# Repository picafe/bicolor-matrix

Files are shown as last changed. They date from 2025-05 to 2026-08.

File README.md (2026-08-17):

# bicolor-matrix

> **This repository has moved to [bicolor-matrix-v2](https://github.com/picafe/bicolor-matrix-v2).**

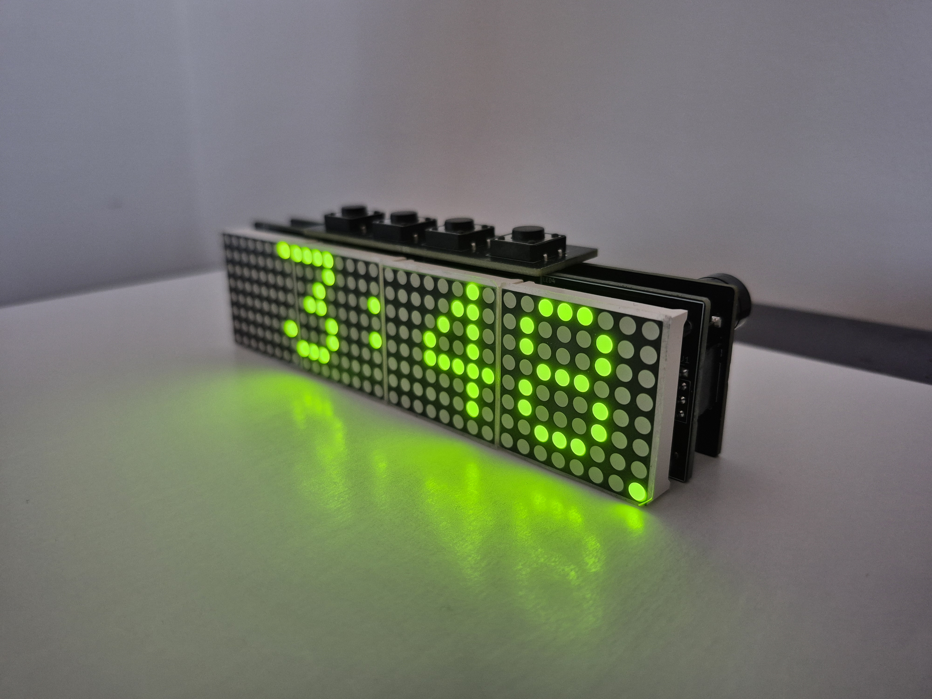
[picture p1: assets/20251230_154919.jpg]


A 32x8 bicolor LED matrix module composed of 4 8x8 matrices based on the Holtek HT16K33A I2C LED driver.

## Inspiration

Inspired by the common 32x8 red LED matrix modules that use the MAX7219 IC, I wanted to make my own module but with more colours and functionality, while keeping the same asthetic. 

I found [these](https://www.aliexpress.com/item/1005007029570407.html) modules while browsing Aliexpress and thought they could look be a cool alternative. With the red and light green variant, you can have red, a light green, and orange all in one module. As far as I'm aware, there aren't RGB modules in a similar form factor, although you can take generic WS2818 8x8 matricies and 3D print a diffuser for them, although the footprint is much bigger. This project was also partially inspired by [bitluni's LED magnet tiles](https://www.youtube.com/watch?v=L2J_eNgjxio) which I found really cool.

Unlike the single colour matricies with 16 pins, these had 24. I found [this](https://www.adafruit.com/product/902) Adafruit module and followed a similar schematic with the Holtek HT16K33A I2C LED driver, but with an inverted board layout, and with 4 modules on one PCB. This was my 2nd PCB project, so it was definately a big undertaking.

## Showcase

Matrix Board:
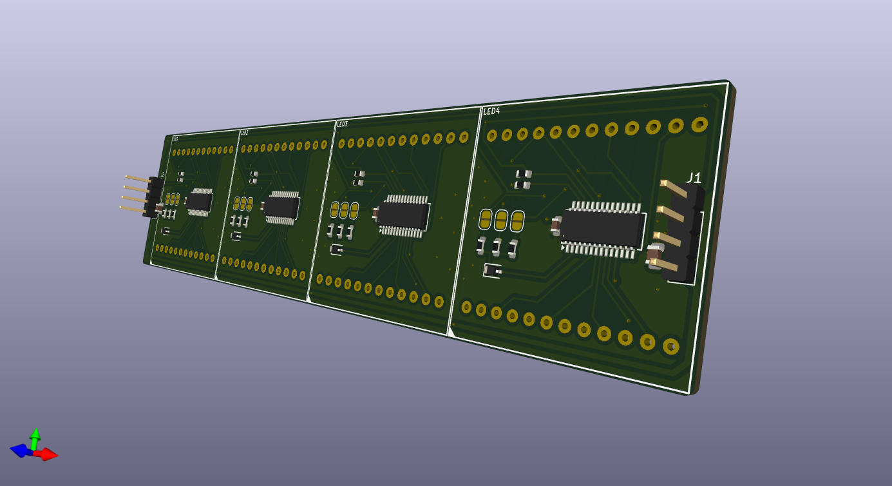
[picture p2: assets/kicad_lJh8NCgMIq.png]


Adapter Board:
This adds functionality through a RP2040 Zero board, a DS3231 module and a small buzzer, and a generic logic level shifter since the Holtek IC only operates near 5V.

Button Board:
An addition to the adapter board and provides 4 interface buttons for setting time

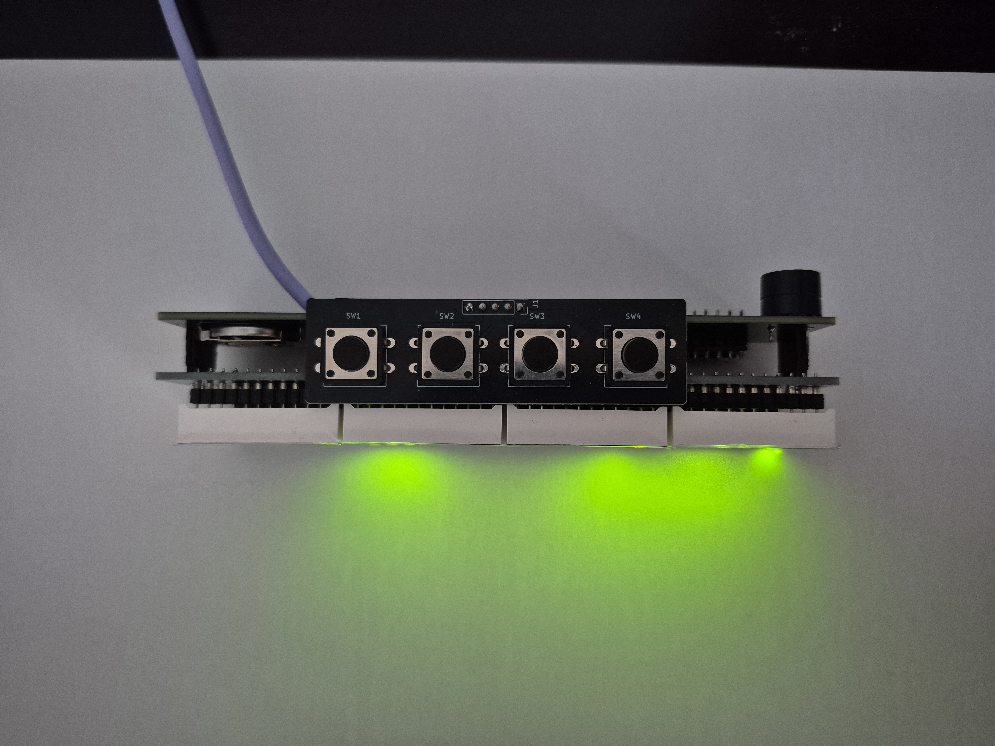
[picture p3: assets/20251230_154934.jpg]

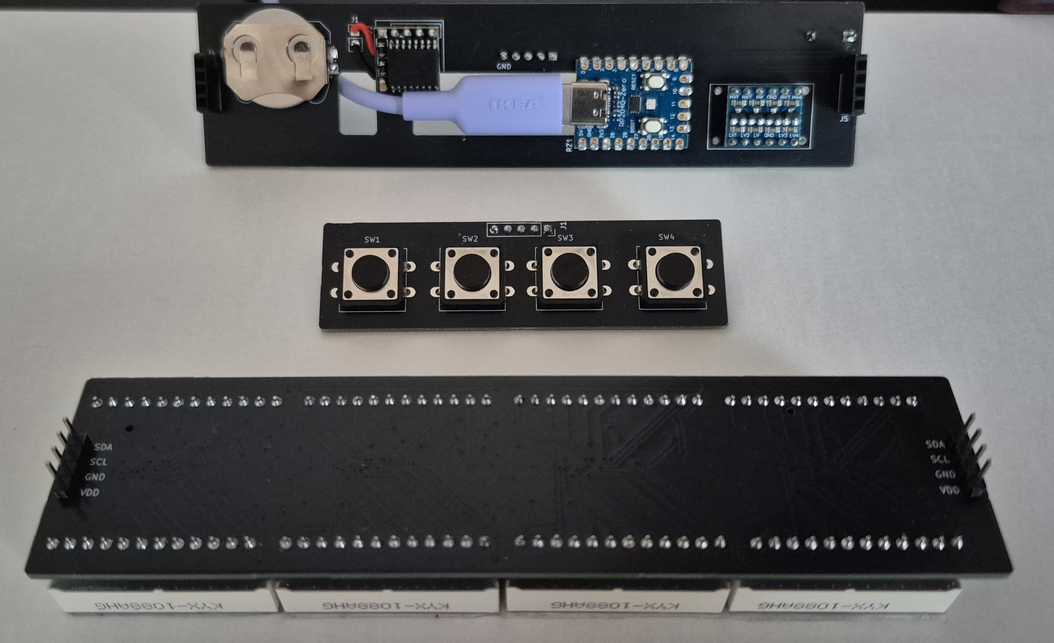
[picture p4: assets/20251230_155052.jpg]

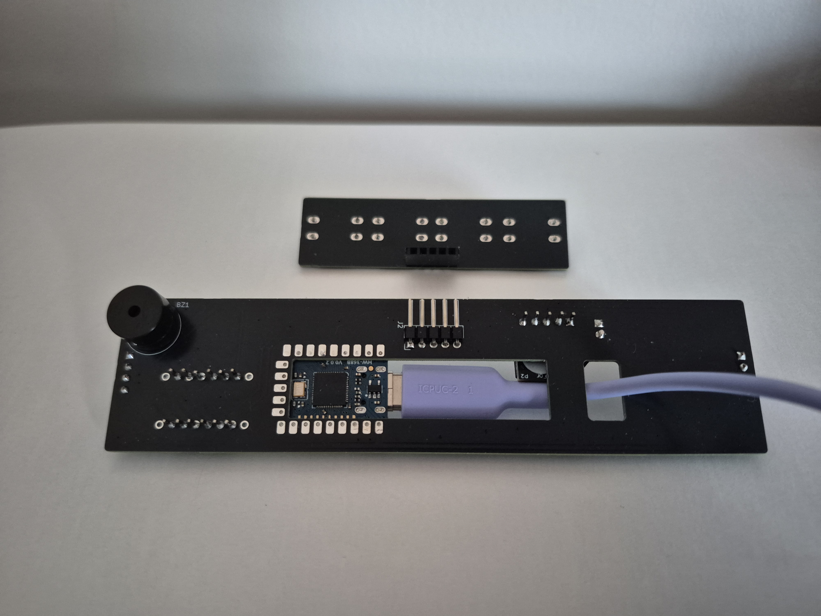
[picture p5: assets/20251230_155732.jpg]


## Bill of Materials (BOM) + Assembly Notes
Item | Quantity | Description
| -------- | ------- | ------- |
[Machine Pin Headers](https://www.aliexpress.com/item/10000000838267.html) | 5 Pcs | 2.54mm pitch circular pin headers to connect the LED matricies to the main PCB. These are needed such as to not solder the matrix boards directly to the PCB, allowing for easier replacement if needed.
12mm x 12mm Buttons | 4 | Generic 12mm tactile push buttons, whatever is cheapest on Aliexpress. I used [these](https://www.aliexpress.com/item/10000000838267.html).
RP2040 Zero | 1 | Microcontroller board, whatever is cheapest on Aliexpress. I bought from [here](https://www.aliexpress.com/item/1005007650325892.html).
[DS3231 Module](https://www.aliexpress.com/item/1005007143842437.html) | 1 | Mini module without the battery, basically a simple breakout. Use side cutters to cut the plastic on the pre-soldered female headers, then desolder each of the pins. Solder in male headers.
Level Shifter | 1 | 4-channel logic level shifter module, whatever is cheapest on Aliexpress. They are cheapest in packs of 10, so you can use the extra ones for other projects. I bought from [here](https://www.aliexpress.com/item/1005006765742290.html).
Buzzer | 1 | Generic 3.3V 7.6mm diameter buzzer, whatever is cheapest on Aliexpress.
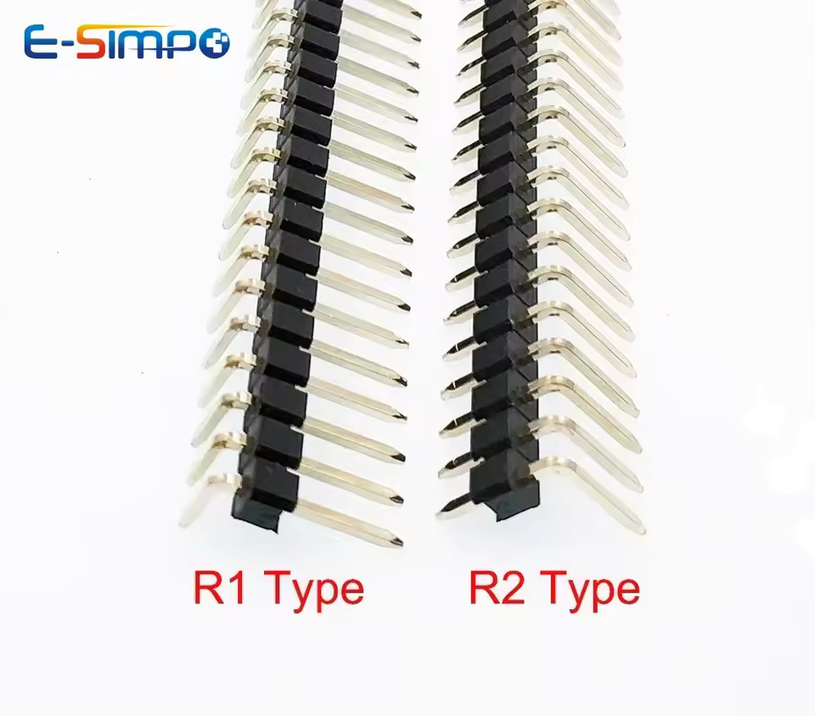
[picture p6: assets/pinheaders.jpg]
[Right Angle Pin Headers](https://www.aliexpress.com/item/32896209964.html) | 1 | Get the R1 type of pin headers pictured here, they're slightly more uncommon and more expensive than the R1 type. This is for the button board connection. 
2.54mm Pin Headers (Male and Female) | 1 | To connect the matrix board to the adapter board and general use. This [video](https://www.youtube.com/watch?v=qDG3VFSMSPQ) shows how to make custom length female headers.

Buying Note: I recommend you try to buy components on the Aliexpress mobile app (web on desktop doesn't seem to have a search bar) in Bundle Deals if you can find them as you can get better prices, and they usually ship faster.

Ordering Note: I recommend you to create your own adapter board for the project. The one I built has some design flaws (button board doesn't fit flush with the adapter board, the right angle headers need to be positioned lower, and usb connector placement could be improved).

It was designed to be a prototype and optimize costs, so I recommend you to make your own design based on your needs. I was browsing Aliexpress a few days ago and found this [RP2350 stamp module](https://www.aliexpress.com/item/1005008513193739.html) which would make a better alternative since you can position the USB connector anywhere on the PCB. It's also relatively cheap.

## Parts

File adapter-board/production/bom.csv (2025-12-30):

Designator | Footprint | Quantity | Value | LCSC Part #
BT1 | BatteryHolder_Keystone_3034_1x20mm | 1 | Battery_Cell
BZ1 | Buzzer_12x9.5RM7.6 | 1 | Buzzer
J1 | PinHeader_1x02_P2.54mm_Vertical | 1 | Conn_01x02_Socket
J2 | PinHeader_1x05_P2.54mm_Horizontal | 1 | Conn_01x05_Pin
J4, J5 | PinSocket_1x04_P2.54mm_Vertical | 2 | Conn_01x04_Socket
RZ1 | RP2040-Zero | 1 | RP2040-Zero
U1 | Generic-Level-Shifter | 1 | ~
U2 | PinHeader_1x05_P2.54mm_Vertical | 1 | ~

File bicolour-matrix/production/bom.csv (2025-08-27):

Designator | Footprint | Quantity | Value | LCSC Part #
C1, C6 | C_0805 | 2 | 10uF | C15850
C2, C3, C4, C5 | C_0603 | 4 | 1uF | C15849
D1, D2, D3, D4 | D_SOD-323 | 4 | 1N4148WS | C2128
J1, J2 | PinHeader_1x04_P2.54mm_Vertical | 2 | Conn_01x04_Pin
LED1, LED2, LED3, LED4 | SEGMENT_BICOL_BL-M12A883XX | 4 | DISP_SEGMENT_8X8_BICOLOR_ROWCATHODEMI2A883XX
R1, R12, R16, R17, R2, R6, R7, R8 | R_0603 | 8 | 4.7kΩ | C23162
R10, R11, R13, R14, R15, R18, R19, R20, R3, R4, R5, R9 | R_0603 | 12 | 47kΩ | C25819
U1, U2, U3, U4 | SSOP-28_3.9x9.9mm_P0.635mm | 4 | HT16K33A-28SSOP | C5444738

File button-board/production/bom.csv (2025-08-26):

Designator | Footprint | Quantity | Value | LCSC Part #
J1 | PinSocket_1x05_P2.54mm_Vertical | 1 | Conn_01x05_Socket
SW1, SW2, SW3, SW4 | SW_PUSH-12mm | 4 | SW_Push

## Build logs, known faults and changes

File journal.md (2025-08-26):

---
Title: "Bicolour Matrix PCB"
Author: "Surya"
Description: "Red and Green LED 32x8 Matrix with HT16K33A"
Created On: "19/5/2025"
---

## 2025-05-19
Four years ago, I built a custom clock with off-the-shelf parts (Arduino Nano, DS3231 breakout, 32x8 MAX7219 LED Matrix, all on a breadboard with 2 buttons). Although it has worked very reliably, only needing a few battery replacements and resetting the nano a few times, I want to make a custom solution.

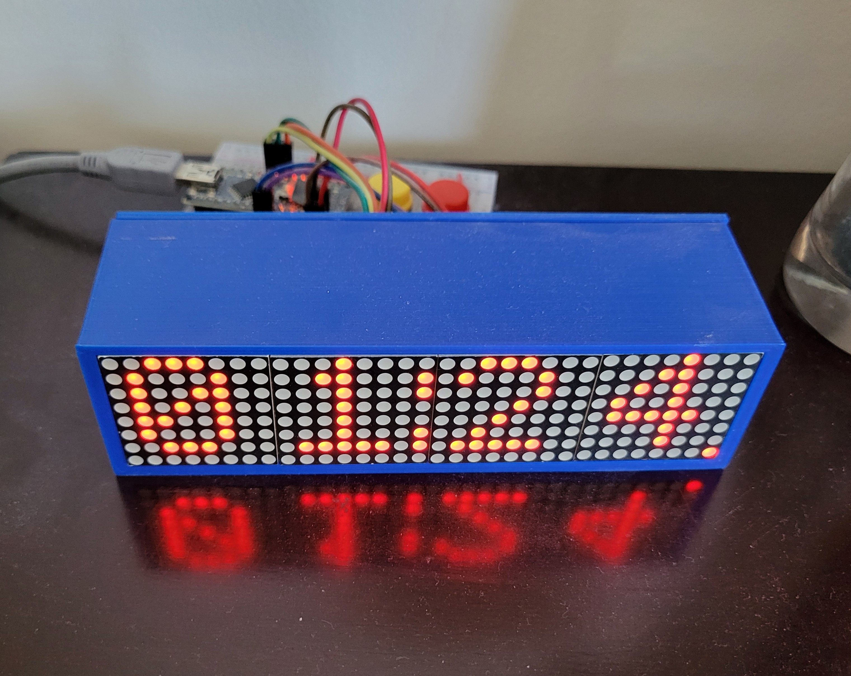
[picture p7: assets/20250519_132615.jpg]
A simple clock with a LED matrix with the current time in a blue case. An Arduino Nano and other components are in the background.

*the current solution ✨*

### Plans
Displays: https://www.aliexpress.com/item/1005007029570407.html
bicolour 8x8 led matrix !! (Red Yellow Green CC)
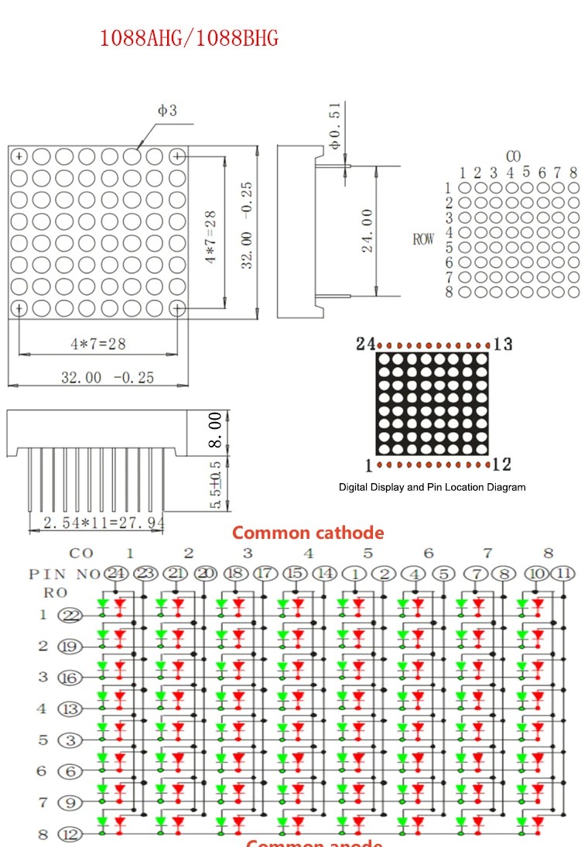
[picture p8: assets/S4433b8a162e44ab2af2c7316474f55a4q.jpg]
 \
Controller: Holtek HT16K33A
https://www.holtek.com/webapi/116711/HT16K33Av102.pdf
likely going to take inspiration from here: 
- https://www.adafruit.com/product/902
- https://learn.adafruit.com/adafruit-led-backpack/bi-color-8x8-matrix

Display Schematic (from Adafruit):
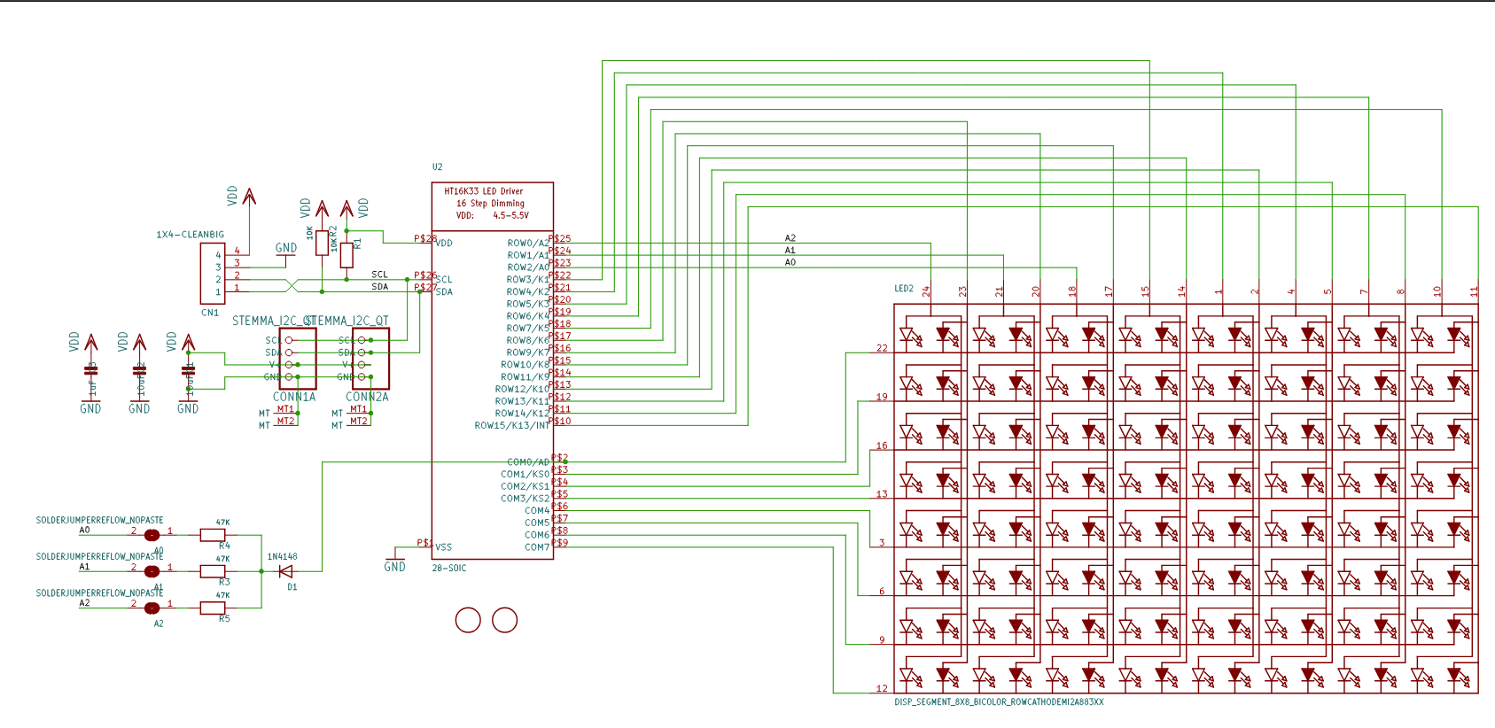
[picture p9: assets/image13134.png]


Using these connections (no STEMMA connectors, just 4 ICs wired on a PCB to same I2C bus with different addresses hard-set on each IC), I will probably make a similar PCB layout with these segments + a microcontroller (possibly a SMD rp2040-zero) with a RTC module and battery slot + controlls for time adjustment and screen brightness controll + an alarm feature. \
I could also use an ESP32 XIAO board and make a feature to add alarms with your phone (maybe also experiment with Zigbee?). I shall see. \
All rough ideas for now, I have some parts in mind but I will likely have to order the screens and a HT16K33(A) breakout board (https://www.aliexpress.com/item/1005006831500717.html) to see if this idea is feasible. If it is, this will be pretty epic.

hours spent: 4

## 2025-05-22
Ordered the 10 pack of LED matricies and the HT16K33 breakout board. I'll prototype with it and build a schematic based on that. The cost of the other components will likely not be much. Not much else for today.

hours spent: n/a

## 2025-05-26
I found this video a few days ago that popped into my YT rec: https://www.youtube.com/watch?v=7fNYj0EXxMs. The PCB design was shown for a few seconds and its quite interesting since he uses the same Holtek driver (along with an I2C address translator; LTC4316) to drive a row of 8 displays, each with 20 pins: 
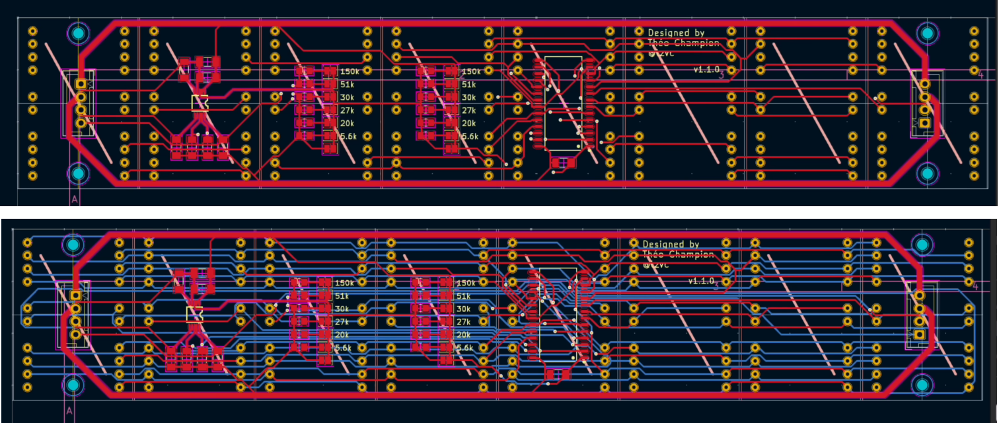
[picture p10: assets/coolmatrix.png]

I'll try and see what magic was performed here (since idk much about this) and see if I can emulate it !!
update: I decided to just go with 4 ICs chained together this is probably beyond my scope

hours spent: n/a

## 2025-05-30
The shipment of the LED matricies and breakout board arrived!! I will assemble them soon (according to the Adafruit schematic) with an arduino nano probably to test. One thing I noticied is that the breakout is kinda sketchy in quality (ive never seen such a thin pcb). Anwyays, it should be fine.

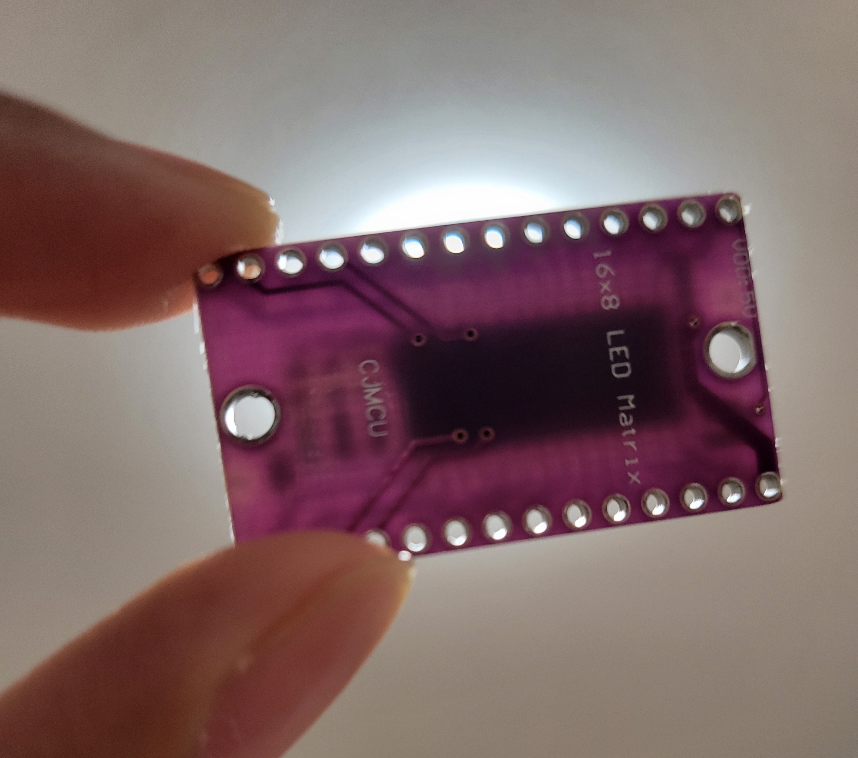
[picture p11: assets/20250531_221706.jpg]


hours spent: n/a

## 2025-06-03
Finally got time to wire everything together. Took me roughly 2hrs to make all the breadboard connections according to the schematic. But it works!\

I tested using the Adafruit example sketch. There are some buggy sections which I'll have to look into later, but for now it looks promising. I guess it's PCB design time. My updates might be less frequent since I'll be busy with a bunch of things.

hours spent: 2.5

## 2025-06-12
Its been a while (got busy) but finally got around to making the schematic (I made one copy and then copy pasted it 4 times; it should work for now). It took be a bit to import the LED controller IC symbol from easyeda (setting up easyeda2kicad and downloading plugins and stuff). The routing is kinda messy but we ball. Took me roughly 2-3hrs I lost track. 
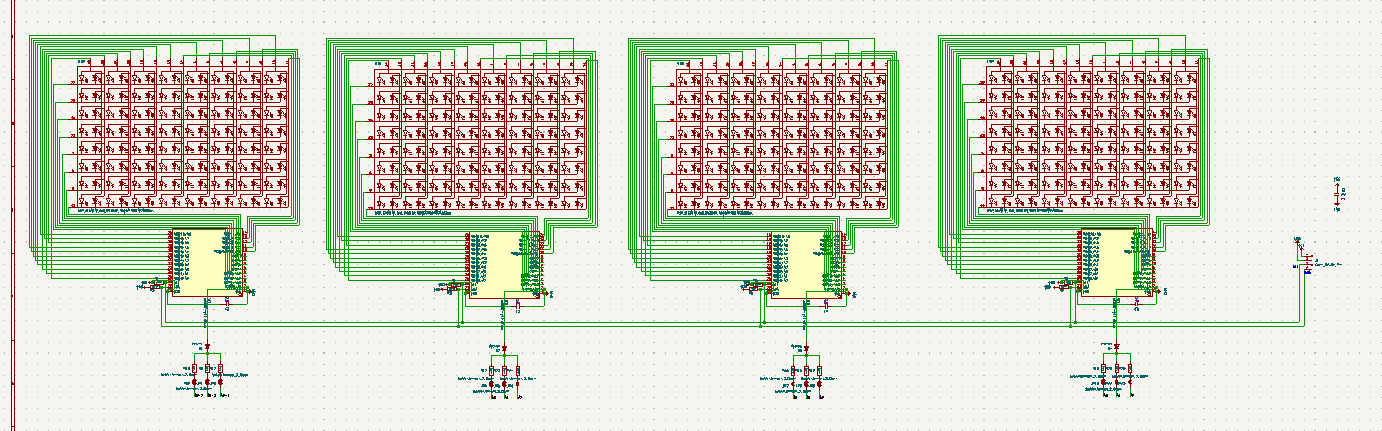
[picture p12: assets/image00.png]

I downloaded and imported the Adafruit board into KiCad so I can reference it while making mine, but my design will be pretty different since they mounted the display on the back of the PCB (mine will be in the front so the pins are mirrored/flipped)
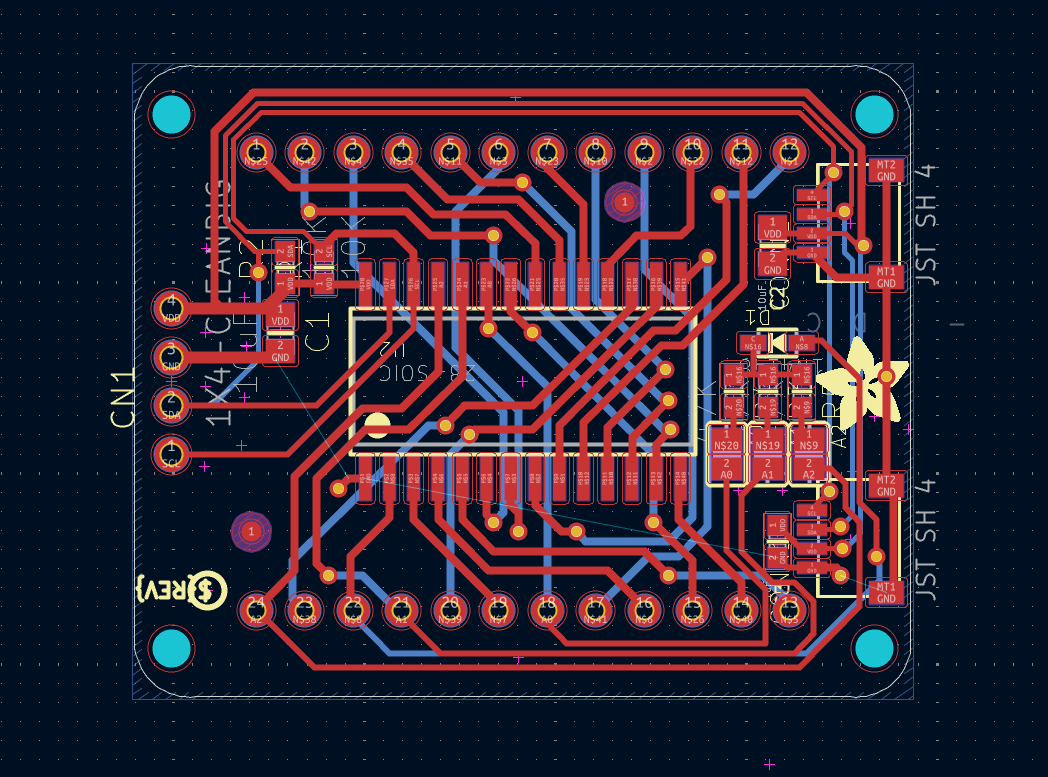
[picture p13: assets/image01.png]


hours spent: 3

## 2025-07-10
OKAY SO life happened. Starting the PCB was quite intimidating so I kind of clicked switch to PCB and left the project for a month. BUT I have convinced myself to get started. And yes it is a lot harder than I thought routing this is pretty pain since I've only done HC solder before. Will prob have to use a lot of vias. Not dealing with any important signals so I should be fine for the most part. \
Slight time skip but no picture for now since I had to delete all my traces a few times. Will be slaving away at this tomorrow.

hours spent: 3

## 2025-07-11
Some progress. Was pain, idk what I'm doing. Not much to say. Took me roughly an hour or 2. 
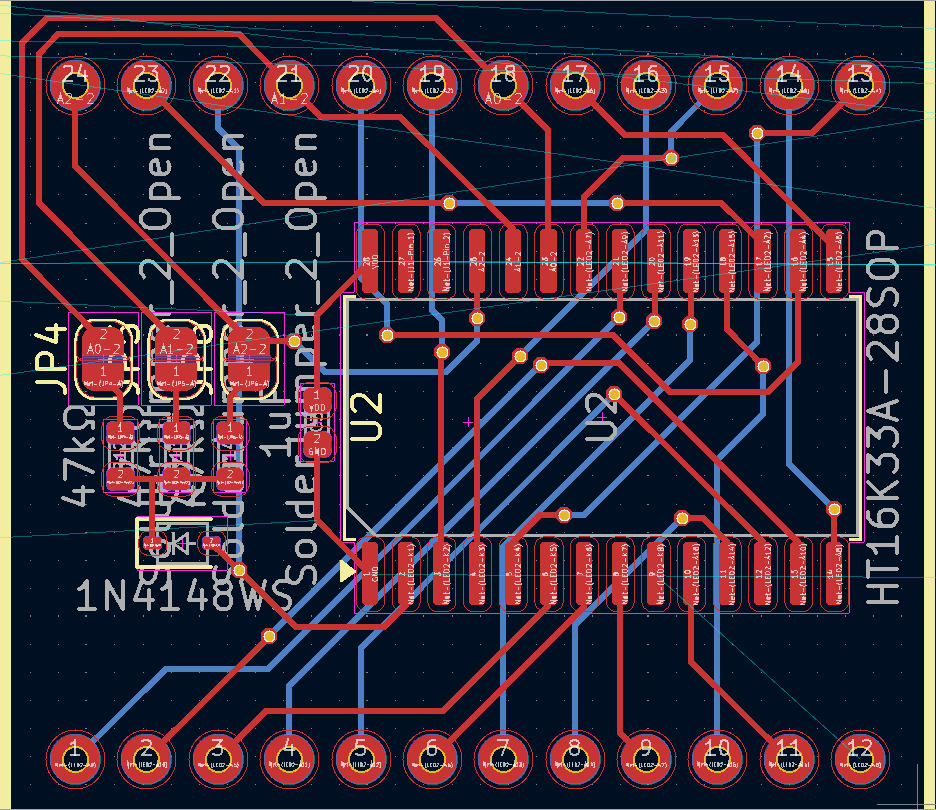
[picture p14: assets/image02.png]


hours spent: 2

## 2025-07-13
OKAY SO AFTER GOING THROUGH ALL THAT... I was using the SOP28 footprint for the LED driver when I meant to use SSOP28. Welp.. time to restart the routing again. Actually I'll do this tomorrow I'm tired.

hours spent: 1

## 2025-07-14
Honestly after this much practice, this is becoming not as hard anymore !! \
managed to get some decent progress:
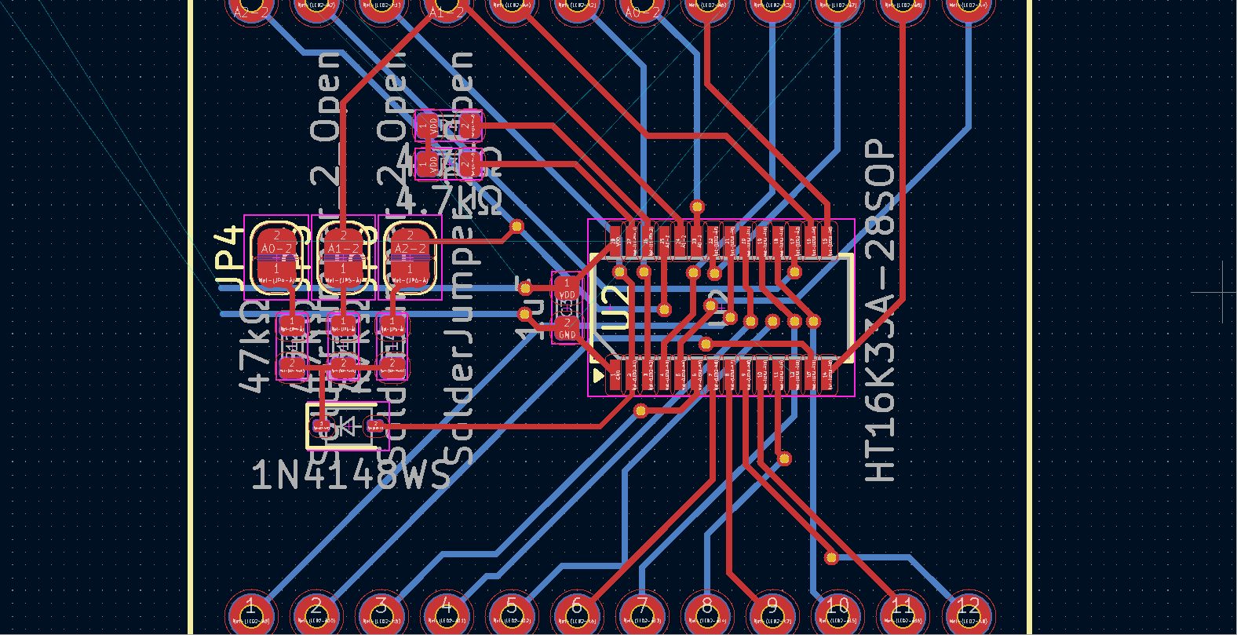
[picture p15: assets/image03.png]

took about 2hrs

hours spent: 2

## 2025-07-15
Finally pretty much done one module, but now I've realized that I can't really copy-paste the design over. I gotta use layout replication (https://www.youtube.com/watch?v=DBfI2wwno5o) and using a custom goofy schematic size wasn't the best idea. I thought I could get away with the jank 😔. I will do that soon. I will also upload the PCB to this repo soon but I'm editing this on WSL and my project folder is on Windows so I got a bit lazy in doing that until now.
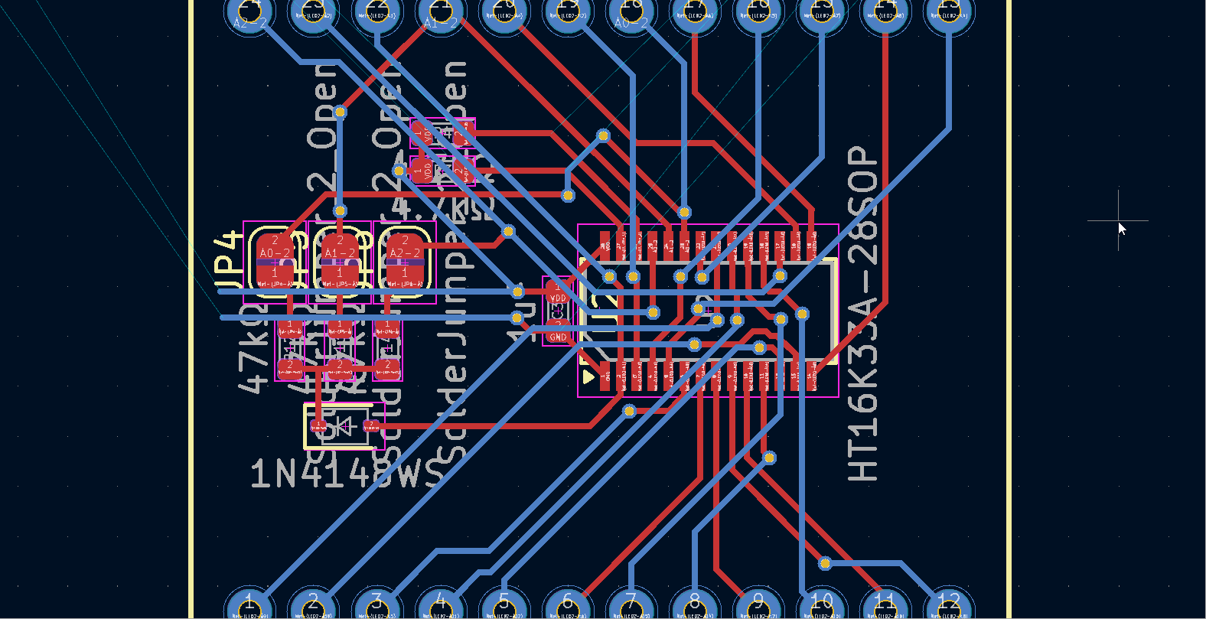
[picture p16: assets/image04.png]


hours spent: 2

## 2025-08-10
I just restarting working on it :pf:. Yet again got busy. Anyways, finally setup the replicate layout plugin (the guide was useful) and managed to 4x the layout properly. It took quite a while. I have yet to put the routing for connecting them all together, (and I still have no clue what I'm doing) but overall good progress today.

hours spent: 2

## 2025-08-12
Got some feedback from a friend and adjusted my routing a bit, and also synced it with the other 4 modules. I tried to route the power/gnd/i2c lines but my routing seems very sketchy. I'll try to improve on it tomorrow. Not much else to say.
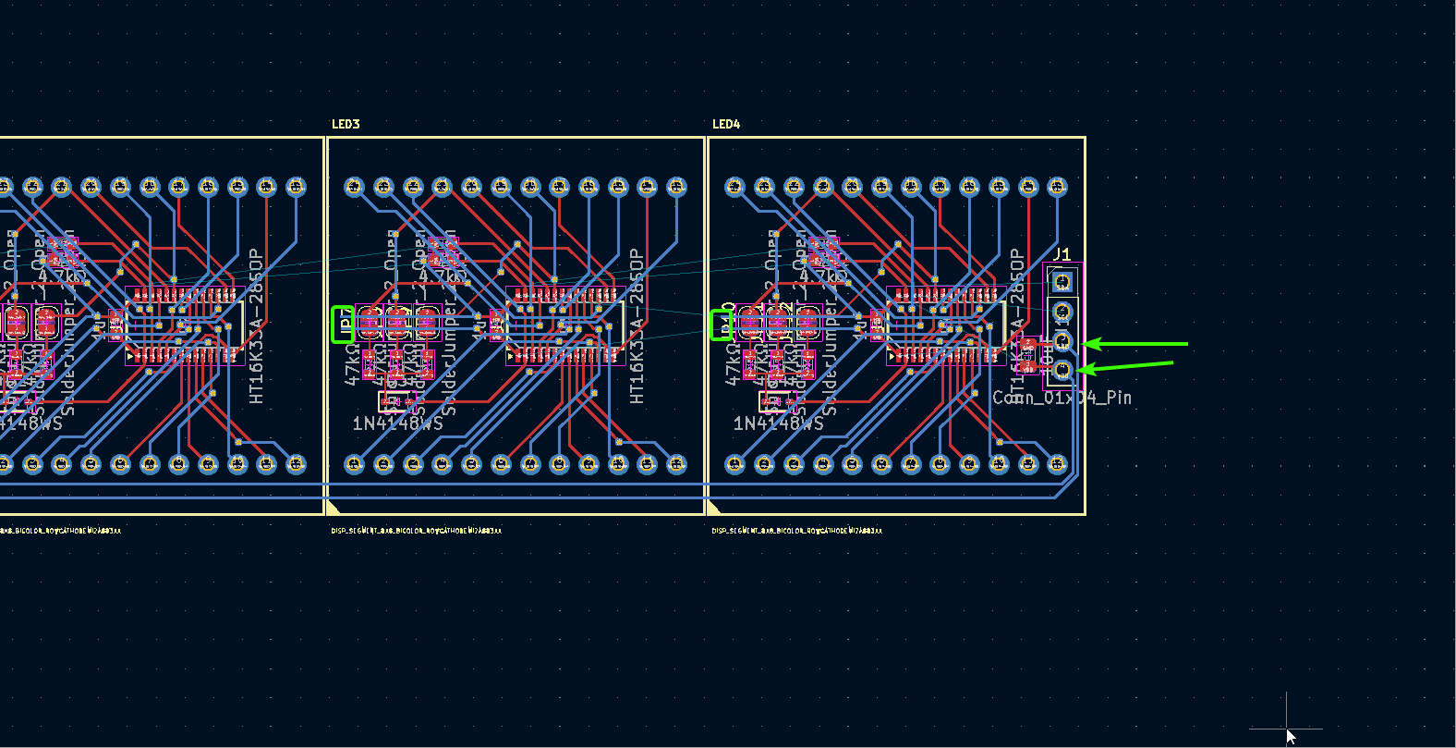
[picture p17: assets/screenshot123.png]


hours spent: 1

## 2025-08-13
I got some feedback from the Slack and added stitching vias to my ground plane (I did not know these were a thing). I also improved my layout further in terms of connecting it all together and adding polish (rounded corners, silkscreen, fixing small DRC warnings, etc.).

hours spent: 1.5

## 2025-08-15
Got some more feedback and everything seems to be good. I will verify the connections in the schematic a last time before I mark this part of the project as done. I also created the project and for now the schematic for the adapter/driver board to make a simple but smart clock. I'll add my sketches later but the 2 boards will probably be the same size with standard headers and I can right angle mount a top board with 2 headers using some right angle header pins I have. I just have to make sure the measurements are right.

hours spent: 1

## 2025-08-19
Just started to work on the adapter board. The schematic was quite easy to make but had to make a real quick custom symbol for the DS3231 module I already had. It's slightly scuffed but not too bad. I'm thinking of using an ESP32 as clicking a bunch of buttons to set an alarm seems cumbersome especially since I usually don't have a static alarm time. It feels like something easier set on your phone. I don't have much more time today so I will start the PCB tomorrow.
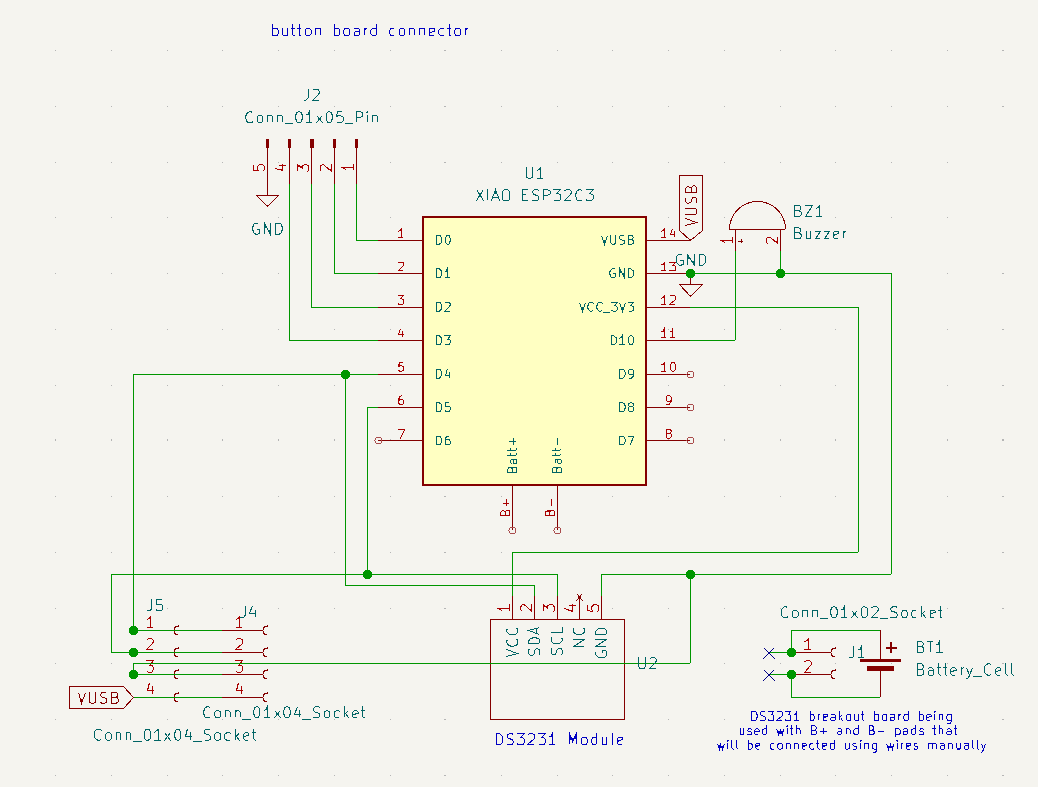
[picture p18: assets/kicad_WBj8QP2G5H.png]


hours spent: 1

## 2025-08-19

I thought of adding a small breadboard-style layout to the PCB if i wanted to tack on some components in the future with some wires. Made a quick custom footprint for that (and random symbol since it doesn't really matter).
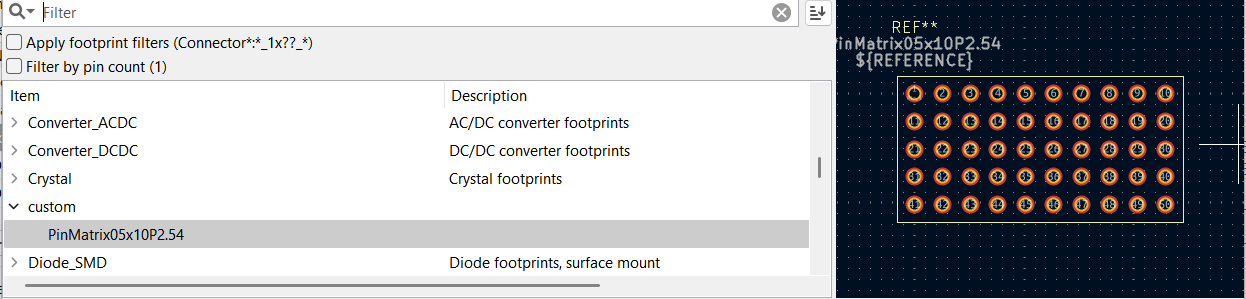
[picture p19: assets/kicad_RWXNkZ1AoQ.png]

I started work on the PCB and I've gotten decent progress. I want to power the thing through the USB on the ESP32, so I am trying to add clearance for that. The range doesn't have to be amazing since I very likely won't be setting my alarm from another room. This is more of a personally tailored PCB rather than something that suits everyone.

hours spent: 2

# 2025-08-21

I originally only allocated space for 2 buttons, but later changed it to 4, since I'll probably need more for the function I want. I don't like the idea of having the time to be dependent on the internet, so I'd like the option to set time time up up/down controls, a button to switch the display colours and a button to toggle/snooze the alarm. I am mostly done the PCB I believe.

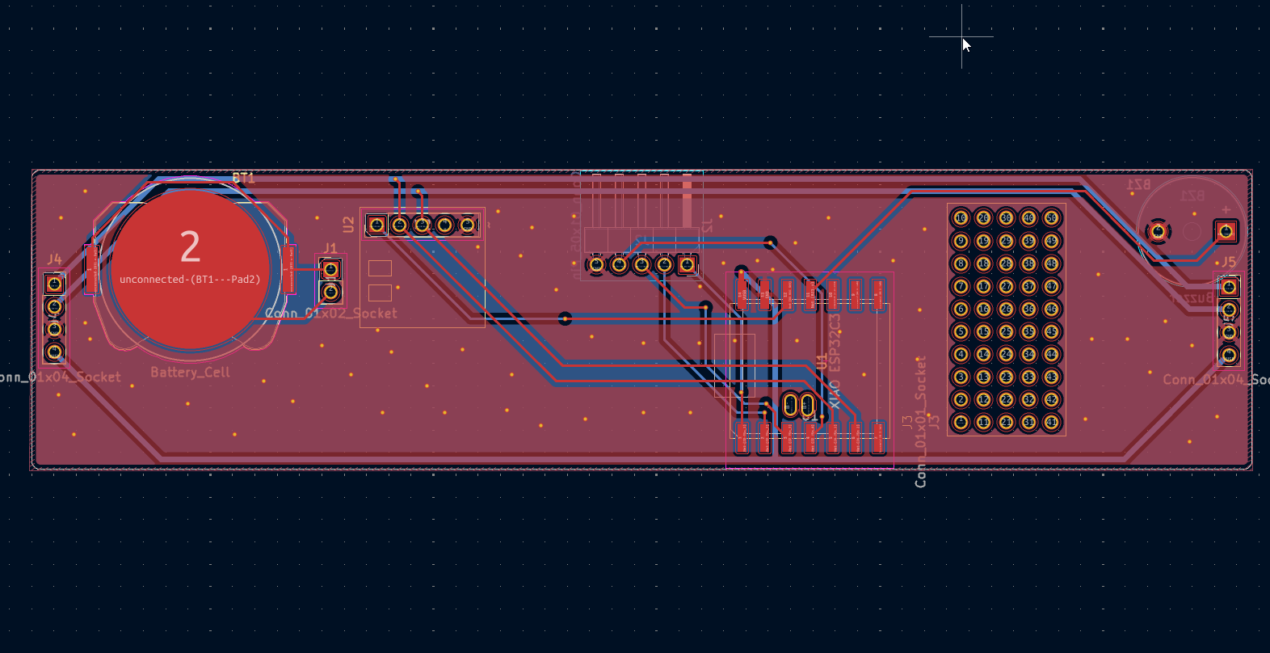
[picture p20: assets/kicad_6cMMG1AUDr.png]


I realized my prototype I made a whie ago wasn't really working properly so I got a bit worried and decided to rewire the entire thing according to the schematic. Turns out I misread a pin due to the bad silkscreen on the breakout board I got... so now it actually works. At least now I have confirmation my schematic works. I also wired up the RTC module and used claude to make a quick test program; everything works fine!! (extra stuff in picture is from other projects/random leftovers)
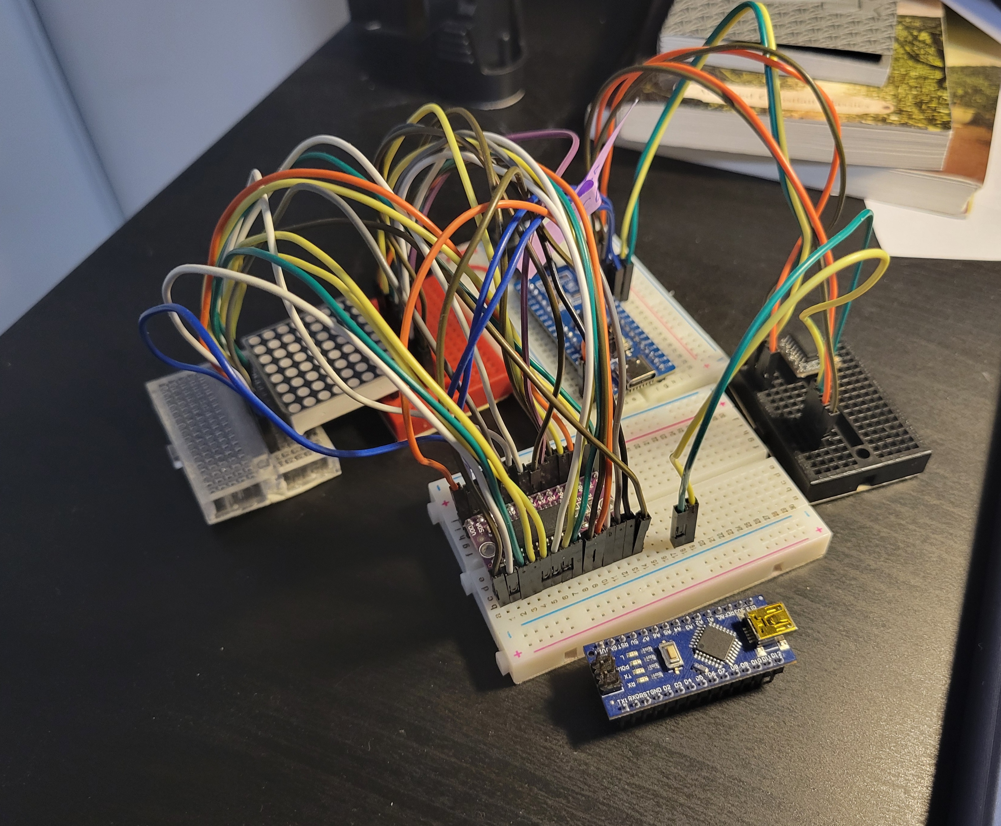
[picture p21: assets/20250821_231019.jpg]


hours spent: 3.5

# 2025-08-22

Last stretch is the button board, which was very easy to make, just a basic schematic. I measured how long the pinheader would be with my callipers (gap between the adapter and matrix PCB) and its around 18mm, so I made the board roughly that long. Slap in a gound plane and pin socket and simple routing and its done. I should finally be done... yippee !!
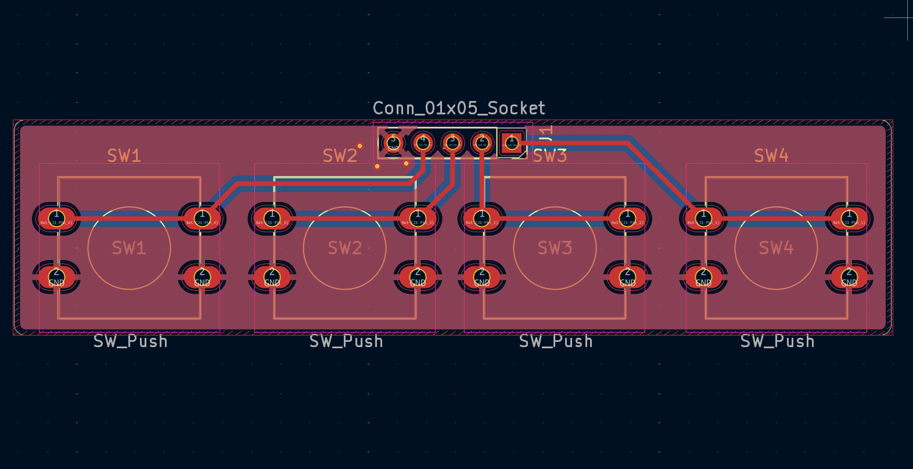
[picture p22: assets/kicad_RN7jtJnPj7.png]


hours spent: 1

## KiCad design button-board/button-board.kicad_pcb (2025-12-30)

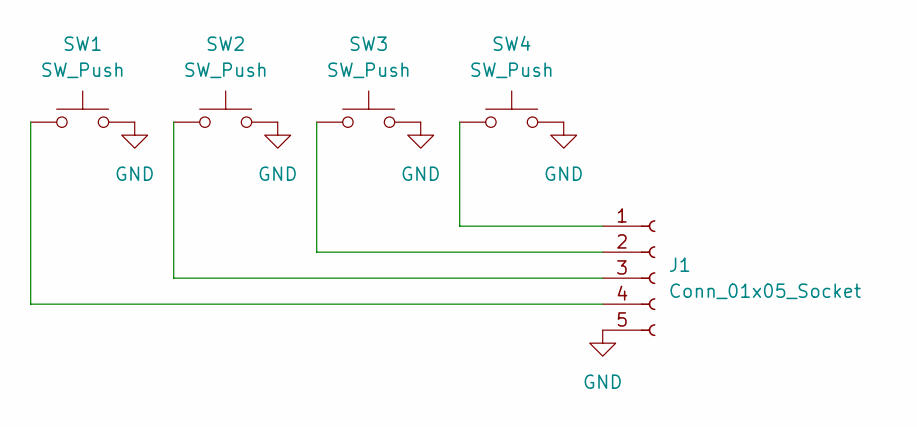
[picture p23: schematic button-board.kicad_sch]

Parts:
J1: Conn_01x05_Socket; PinSocket_1x05_P2.54mm_Vertical
SW1, SW2, SW3, SW4: SW_Push; SW_PUSH-12mm

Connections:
GND: J1.5, SW1.2, SW2.2, SW3.2, SW4.2
unnamed: J1.1, SW4.1
unnamed: J1.2, SW3.1
unnamed: J1.3, SW2.1
unnamed: J1.4, SW1.1

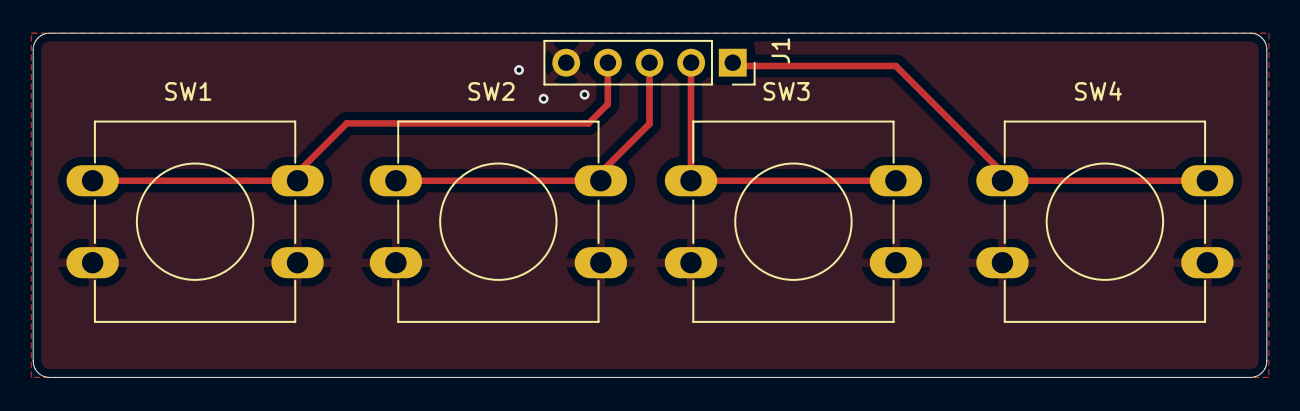
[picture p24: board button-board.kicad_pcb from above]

Board: 2 copper layers, 75.3 x 21.0 mm, 5 parts (0 on the bottom side), 5 nets.

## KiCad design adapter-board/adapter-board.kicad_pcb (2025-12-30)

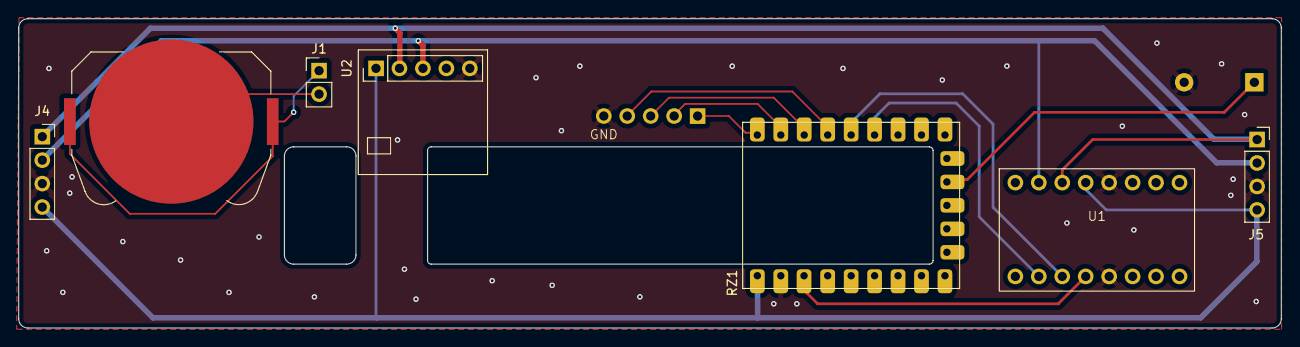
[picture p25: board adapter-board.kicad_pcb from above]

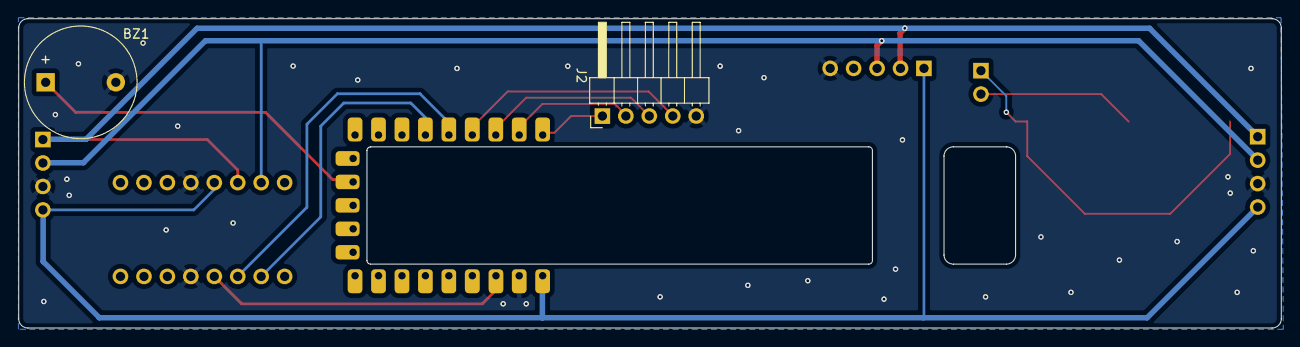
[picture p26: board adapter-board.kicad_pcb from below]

Board: 2 copper layers, 136.8 x 33.5 mm, 9 parts (2 on the bottom side), 12 nets.

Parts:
BT1: Battery_Cell; BatteryHolder_Keystone_3034_1x20mm
BZ1: Buzzer; Buzzer_12x9.5RM7.6
J1: Conn_01x02_Socket; PinHeader_1x02_P2.54mm_Vertical
J2: Conn_01x05_Pin; PinHeader_1x05_P2.54mm_Horizontal
J4, J5: Conn_01x04_Socket; PinSocket_1x04_P2.54mm_Vertical
RZ1: RP2040-Zero
U1: Generic-Level-Shifter
U2: PinHeader_1x05_P2.54mm_Vertical

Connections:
3V3: RZ1.21 (3V3), U1.9 (LV)
GND: BZ1.2 (-), J2.5, J4.3, J5.3, RZ1.22 (GND), U1.4 (GND), U1.10 (GND), U2.5 (GND)
unnamed: BZ1.1 (+), RZ1.11 (GP10)
unnamed: J2.1, RZ1.1 (GP0)
unnamed: J2.2, RZ1.2 (GP1)
unnamed: J2.3, RZ1.3 (GP2)
unnamed: J2.4, RZ1.4 (GP3)
unnamed: J4.1, J5.1, U1.2 (HV2), U2.2 (SDA)
unnamed: J4.2, J5.2, U1.1 (HV1), U2.3 (SCL)
unnamed: RZ1.5 (GP4), U1.8 (LV2)
unnamed: RZ1.6 (GP5), U1.7 (LV1)
VUSB: J4.4, J5.4, RZ1.23 (5V), U1.3 (HV), U2.1 (VCC)

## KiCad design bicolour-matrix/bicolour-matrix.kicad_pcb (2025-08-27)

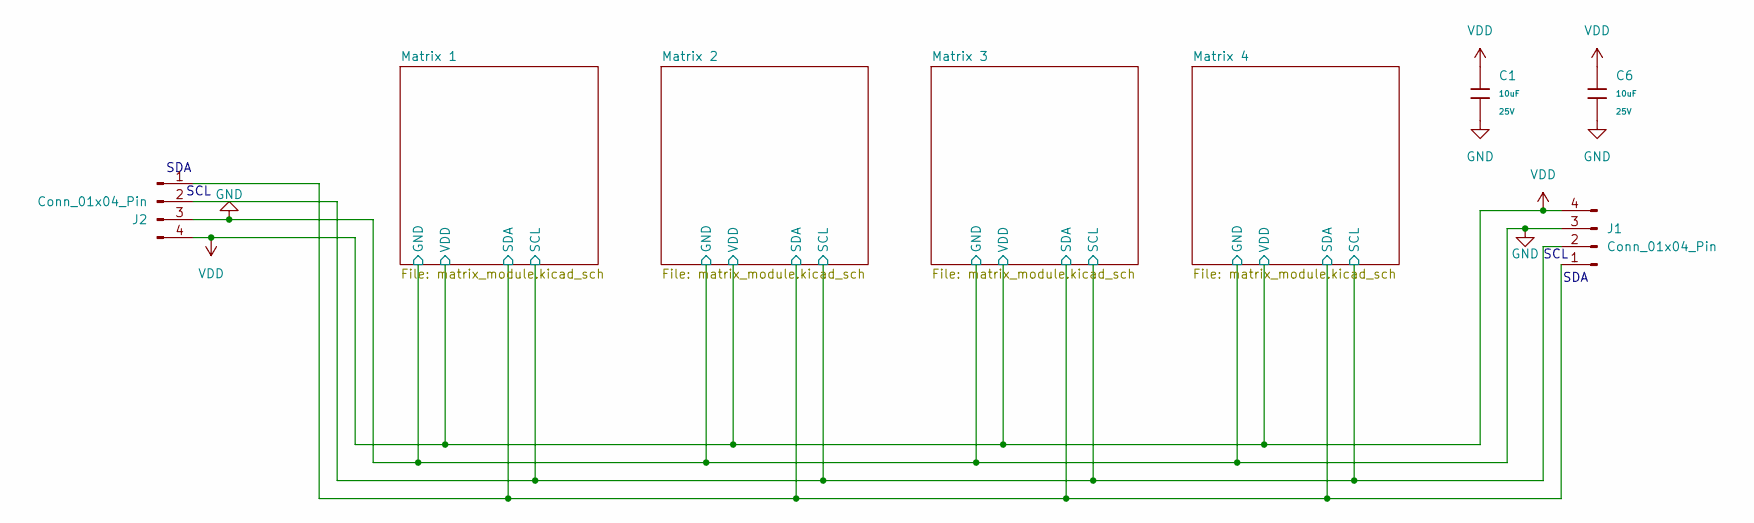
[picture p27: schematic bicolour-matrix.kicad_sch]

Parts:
C1, C6: 10uF; C_0805; Voltage Rated 25V; Tolerance ±10%; Part CL21A106KAYNNNE; LCSC C15850
J1, J2: Conn_01x04_Pin; PinHeader_1x04_P2.54mm_Vertical

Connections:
/Matrix 1/SCL: J1.2, J2.2; also elsewhere on the board
/Matrix 1/SDA: J1.1, J2.1; also elsewhere on the board
GND: C1.2, C6.2, J1.3, J2.3; also elsewhere on the board
VDD: C1.1, C6.1, J1.4, J2.4; also elsewhere on the board

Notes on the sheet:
SCL
SDA

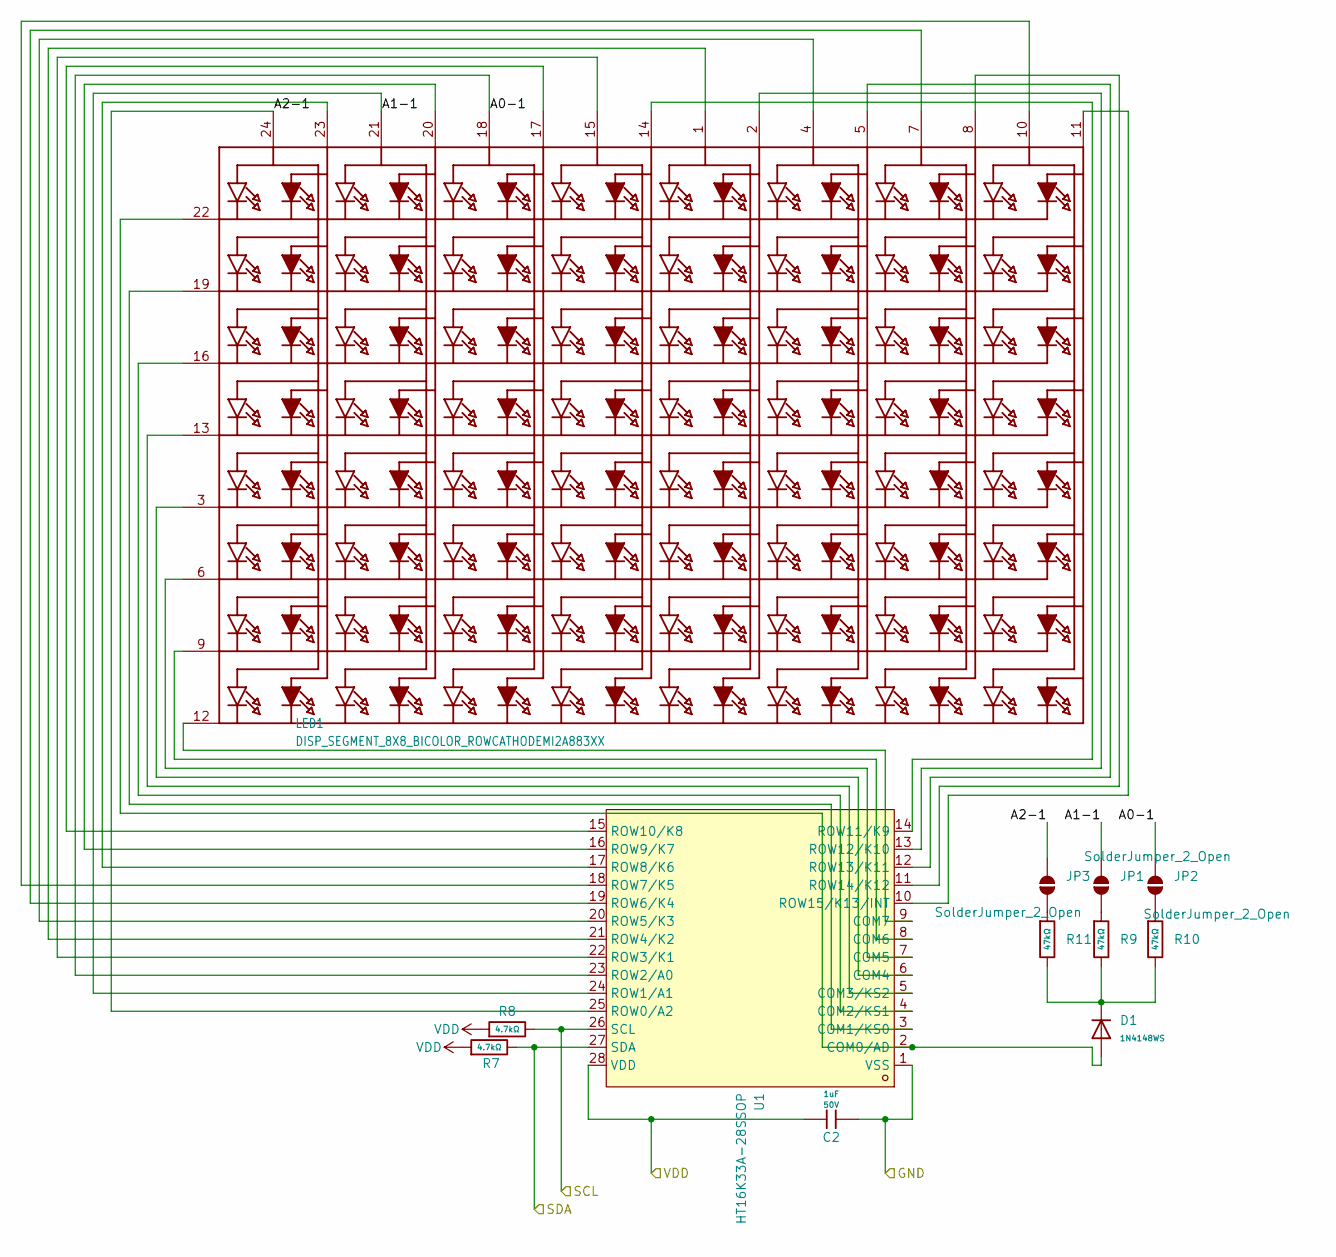
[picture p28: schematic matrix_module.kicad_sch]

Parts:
C2: 1uF; C_0603; Voltage Rated 50V; Tolerance ±10%; Part CL10A105KB8NNNC; LCSC C15849
D1: 1N4148WS; D_SOD-323; Forward Voltage (Vf@If) 1.25V@150mA; Reverse Voltage (Vr) 100V; Part 1N4148WS; LCSC C2128
JP1, JP2, JP3: SolderJumper_2_Open; SolderJumper-2_P1.3mm_Open_RoundedPad1.0x1.5mm
LED1: DISP_SEGMENT_8X8_BICOLOR_ROWCATHODEMI2A883XX; SEGMENT_BICOL_BL-M12A883XX
R7, R8: 4.7kΩ; R_0603; Overload Voltage (Max) 75V; Tolerance ±1%; Part 0603WAF4701T5E; LCSC C23162
R9, R10, R11: 47kΩ; R_0603; Overload Voltage (Max) 75V; Tolerance ±1%; Part 0603WAF4702T5E; LCSC C25819
U1: HT16K33A-28SSOP; SSOP-28_3.9x9.9mm_P0.635mm; LCSC Part C5444738

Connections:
/Matrix 1/A0-1: JP2.2 (B), LED1.18 (A5), U1.23 (ROW2/A0)
/Matrix 1/A1-1: JP1.2 (B), LED1.21 (A3), U1.24 (ROW1/A1)
/Matrix 1/A2-1: JP3.2 (B), LED1.24 (A1), U1.25 (ROW0/A2)
/Matrix 1/SCL: R8.2, U1.26 (SCL); also elsewhere on the board
/Matrix 1/SDA: R7.2, U1.27 (SDA); also elsewhere on the board
GND: C2.2, U1.1 (VSS); also elsewhere on the board
unnamed: D1.1, R9.2, R10.2, R11.2
unnamed: JP1.1 (A), R9.1
unnamed: JP2.1 (A), R10.1
unnamed: JP3.1 (A), R11.1
unnamed: LED1.23 (A2), U1.17 (ROW8/K6)
unnamed: LED1.20 (A4), U1.16 (ROW9/K7)
unnamed: LED1.17 (A6), U1.15 (ROW10/K8)
unnamed: LED1.15 (A7), U1.22 (ROW3/K1)
unnamed: LED1.14 (A8), U1.14 (ROW11/K9)
unnamed: LED1.1 (A9), U1.21 (ROW4/K2)
unnamed: LED1.2 (A10), U1.13 (ROW12/K10)
unnamed: LED1.4 (A11), U1.20 (ROW5/K3)
unnamed: LED1.5 (A12), U1.12 (ROW13/K11)
unnamed: LED1.7 (A13), U1.19 (ROW6/K4)
unnamed: LED1.8 (A14), U1.11 (ROW14/K12)
unnamed: LED1.10 (A15), U1.18 (ROW7/K5)
unnamed: LED1.11 (A16), U1.10 (ROW15/K13/INT)
unnamed: D1.2, LED1.22 (K1), U1.2 (COM0/AD)
unnamed: LED1.19 (K2), U1.3 (COM1/KS0)
unnamed: LED1.16 (K3), U1.4 (COM2/KS1)
unnamed: LED1.13 (K4), U1.5 (COM3/KS2)
unnamed: LED1.3 (K5), U1.6 (COM4)
unnamed: LED1.6 (K6), U1.7 (COM5)
unnamed: LED1.9 (K7), U1.8 (COM6)
unnamed: LED1.12 (K8), U1.9 (COM7)
VDD: C2.1, R7.1, R8.1, U1.28 (VDD); also elsewhere on the board

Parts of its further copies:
C3, C4, C5: 1uF; C_0603; Voltage Rated 50V; Tolerance ±10%; Part CL10A105KB8NNNC; LCSC C15849
D2, D3, D4: 1N4148WS; D_SOD-323; Forward Voltage (Vf@If) 1.25V@150mA; Reverse Voltage (Vr) 100V; Part 1N4148WS; LCSC C2128
JP4, JP5, JP6, JP7, JP8, JP9, JP10, JP11, JP12: SolderJumper_2_Open; SolderJumper-2_P1.3mm_Open_RoundedPad1.0x1.5mm
LED2, LED3, LED4: DISP_SEGMENT_8X8_BICOLOR_ROWCATHODEMI2A883XX; SEGMENT_BICOL_BL-M12A883XX
R1, R2, R6, R12, R16, R17: 4.7kΩ; R_0603; Overload Voltage (Max) 75V; Tolerance ±1%; Part 0603WAF4701T5E; LCSC C23162
R3, R4, R5, R13, R14, R15, R18, R19, R20: 47kΩ; R_0603; Overload Voltage (Max) 75V; Tolerance ±1%; Part 0603WAF4702T5E; LCSC C25819
U2, U3, U4: HT16K33A-28SSOP; SSOP-28_3.9x9.9mm_P0.635mm; LCSC Part C5444738

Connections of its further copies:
/Matrix 1/SCL: R2.2, R12.2, R17.2, U2.26 (SCL), U3.26 (SCL), U4.26 (SCL); also elsewhere on the board
/Matrix 1/SDA: R1.2, R6.2, R16.2, U2.27 (SDA), U3.27 (SDA), U4.27 (SDA); also elsewhere on the board
/Matrix 2/A0-1: JP6.2 (B), LED2.18 (A5), U2.23 (ROW2/A0)
/Matrix 2/A1-1: JP5.2 (B), LED2.21 (A3), U2.24 (ROW1/A1)
/Matrix 2/A2-1: JP4.2 (B), LED2.24 (A1), U2.25 (ROW0/A2)
/Matrix 3/A0-1: JP9.2 (B), LED3.18 (A5), U3.23 (ROW2/A0)
/Matrix 3/A1-1: JP8.2 (B), LED3.21 (A3), U3.24 (ROW1/A1)
/Matrix 3/A2-1: JP7.2 (B), LED3.24 (A1), U3.25 (ROW0/A2)
/Matrix 4/A0-1: JP12.2 (B), LED4.18 (A5), U4.23 (ROW2/A0)
/Matrix 4/A1-1: JP11.2 (B), LED4.21 (A3), U4.24 (ROW1/A1)
/Matrix 4/A2-1: JP10.2 (B), LED4.24 (A1), U4.25 (ROW0/A2)
GND: C3.2, C4.2, C5.2, U2.1 (VSS), U3.1 (VSS), U4.1 (VSS); also elsewhere on the board
unnamed: D2.1, R3.2, R4.2, R5.2
unnamed: D3.1, R13.2, R14.2, R15.2
unnamed: D4.1, R18.2, R19.2, R20.2
unnamed: JP4.1 (A), R3.1
unnamed: JP5.1 (A), R4.1
unnamed: JP6.1 (A), R5.1
unnamed: JP7.1 (A), R13.1
unnamed: JP8.1 (A), R14.1
unnamed: JP9.1 (A), R15.1
unnamed: JP10.1 (A), R18.1
unnamed: JP11.1 (A), R19.1
unnamed: JP12.1 (A), R20.1
unnamed: LED2.23 (A2), U2.17 (ROW8/K6)
unnamed: LED2.20 (A4), U2.16 (ROW9/K7)
unnamed: LED2.17 (A6), U2.15 (ROW10/K8)
unnamed: LED2.15 (A7), U2.22 (ROW3/K1)
unnamed: LED2.14 (A8), U2.14 (ROW11/K9)
unnamed: LED2.1 (A9), U2.21 (ROW4/K2)
unnamed: LED2.2 (A10), U2.13 (ROW12/K10)
unnamed: LED2.4 (A11), U2.20 (ROW5/K3)
unnamed: LED2.5 (A12), U2.12 (ROW13/K11)
unnamed: LED2.7 (A13), U2.19 (ROW6/K4)
unnamed: LED2.8 (A14), U2.11 (ROW14/K12)
unnamed: LED2.10 (A15), U2.18 (ROW7/K5)
unnamed: LED2.11 (A16), U2.10 (ROW15/K13/INT)
unnamed: D2.2, LED2.22 (K1), U2.2 (COM0/AD)
unnamed: LED2.19 (K2), U2.3 (COM1/KS0)
unnamed: LED2.16 (K3), U2.4 (COM2/KS1)
unnamed: LED2.13 (K4), U2.5 (COM3/KS2)
unnamed: LED2.3 (K5), U2.6 (COM4)
unnamed: LED2.6 (K6), U2.7 (COM5)
unnamed: LED2.9 (K7), U2.8 (COM6)
unnamed: LED2.12 (K8), U2.9 (COM7)
unnamed: LED3.23 (A2), U3.17 (ROW8/K6)
unnamed: LED3.20 (A4), U3.16 (ROW9/K7)
unnamed: LED3.17 (A6), U3.15 (ROW10/K8)
unnamed: LED3.15 (A7), U3.22 (ROW3/K1)
unnamed: LED3.14 (A8), U3.14 (ROW11/K9)
unnamed: LED3.1 (A9), U3.21 (ROW4/K2)
unnamed: LED3.2 (A10), U3.13 (ROW12/K10)
unnamed: LED3.4 (A11), U3.20 (ROW5/K3)
unnamed: LED3.5 (A12), U3.12 (ROW13/K11)
unnamed: LED3.7 (A13), U3.19 (ROW6/K4)
unnamed: LED3.8 (A14), U3.11 (ROW14/K12)
unnamed: LED3.10 (A15), U3.18 (ROW7/K5)
unnamed: LED3.11 (A16), U3.10 (ROW15/K13/INT)
unnamed: D3.2, LED3.22 (K1), U3.2 (COM0/AD)
unnamed: LED3.19 (K2), U3.3 (COM1/KS0)
unnamed: LED3.16 (K3), U3.4 (COM2/KS1)
unnamed: LED3.13 (K4), U3.5 (COM3/KS2)
unnamed: LED3.3 (K5), U3.6 (COM4)
unnamed: LED3.6 (K6), U3.7 (COM5)
unnamed: LED3.9 (K7), U3.8 (COM6)
unnamed: LED3.12 (K8), U3.9 (COM7)
unnamed: LED4.23 (A2), U4.17 (ROW8/K6)
unnamed: LED4.20 (A4), U4.16 (ROW9/K7)
unnamed: LED4.17 (A6), U4.15 (ROW10/K8)
unnamed: LED4.15 (A7), U4.22 (ROW3/K1)
unnamed: LED4.14 (A8), U4.14 (ROW11/K9)
unnamed: LED4.1 (A9), U4.21 (ROW4/K2)
unnamed: LED4.2 (A10), U4.13 (ROW12/K10)
unnamed: LED4.4 (A11), U4.20 (ROW5/K3)
unnamed: LED4.5 (A12), U4.12 (ROW13/K11)
unnamed: LED4.7 (A13), U4.19 (ROW6/K4)
unnamed: LED4.8 (A14), U4.11 (ROW14/K12)
unnamed: LED4.10 (A15), U4.18 (ROW7/K5)
unnamed: LED4.11 (A16), U4.10 (ROW15/K13/INT)
unnamed: D4.2, LED4.22 (K1), U4.2 (COM0/AD)
unnamed: LED4.19 (K2), U4.3 (COM1/KS0)
unnamed: LED4.16 (K3), U4.4 (COM2/KS1)
unnamed: LED4.13 (K4), U4.5 (COM3/KS2)
unnamed: LED4.3 (K5), U4.6 (COM4)
unnamed: LED4.6 (K6), U4.7 (COM5)
unnamed: LED4.9 (K7), U4.8 (COM6)
unnamed: LED4.12 (K8), U4.9 (COM7)
VDD: C3.1, C4.1, C5.1, R1.1, R2.1, R6.1, R12.1, R16.1, R17.1, U2.28 (VDD), U3.28 (VDD), U4.28 (VDD); also elsewhere on the board

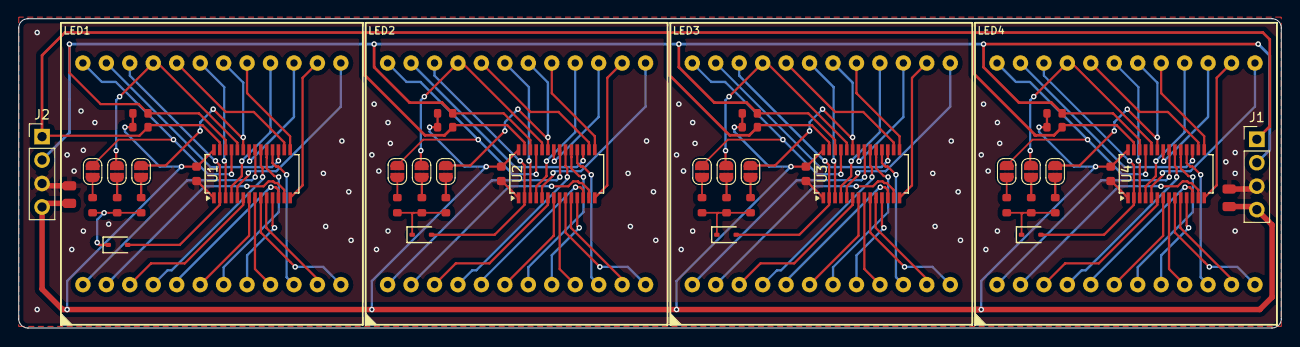
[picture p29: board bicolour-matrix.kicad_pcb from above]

Board: 2 copper layers, 136.8 x 33.5 mm, 52 parts (0 on the bottom side), 116 nets.

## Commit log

2025-08-11 feat: PCB
    [bicolour-matrix.kicad_pcb, bicolour-matrix.kicad_sch, matrix_module.kicad_sch]
2025-08-14 feat: final revs
    [bicolour-matrix.kicad_pcb, bicolour-matrix.kicad_sch]
2025-08-14 feat: gerbers + design feedback
    [bicolour-matrix.kicad_pcb, bom.csv, designators.csv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]
2025-08-16 feat: adapter board
    [adapter-board.kicad_pcb, adapter-board.kicad_sch, bicolour-matrix.kicad_pcb]
2025-08-21 feat: adapter board kicad
    [adapter-board.kicad_pcb, adapter-board.kicad_sch]
2025-08-22 feat: gerbers
    [adapter-board.kicad_pcb, bom.csv, designators.csv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]
2025-08-22 feat: final changes
    [adapter-board.kicad_pcb, adapter-board.kicad_sch, button-board.kicad_pcb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]
2025-08-26 feat: docs + gerbers
    [bicolour-matrix.kicad_pcb, bom.csv, button-board.kicad_pcb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]
2025-08-26 feat: updated gerbers
2025-08-27 feat: fixed lcsc component
    [bicolour-matrix.kicad_pcb, bom.csv, matrix_module.kicad_sch]
2025-12-30 feat: PCB updates
    [adapter-board.kicad_pcb, adapter-board.kicad_sch, bom.csv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]
